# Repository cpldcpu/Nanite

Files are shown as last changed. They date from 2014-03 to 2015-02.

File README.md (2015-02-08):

Nanite 85 
======

The Nanite 85, a nano-sized ATtiny85 devboard with USB Bootloader - most likely the smallest one ever.

The repository holds the Eagle circuit, PCB design data and a software example to handle the soft reset-button.

See [Blog post](http://cpldcpu.wordpress.com/2014/04/25/the-nanite-85/) for more information.

New
===

I teamed up with [Watterott](http://www.watterott.com) on making the Nanite 85 available for everyone. You can get one [here](http://www.watterott.com/de/Wattuino-Nanite85). Note that changes had to be made for manufacturability.

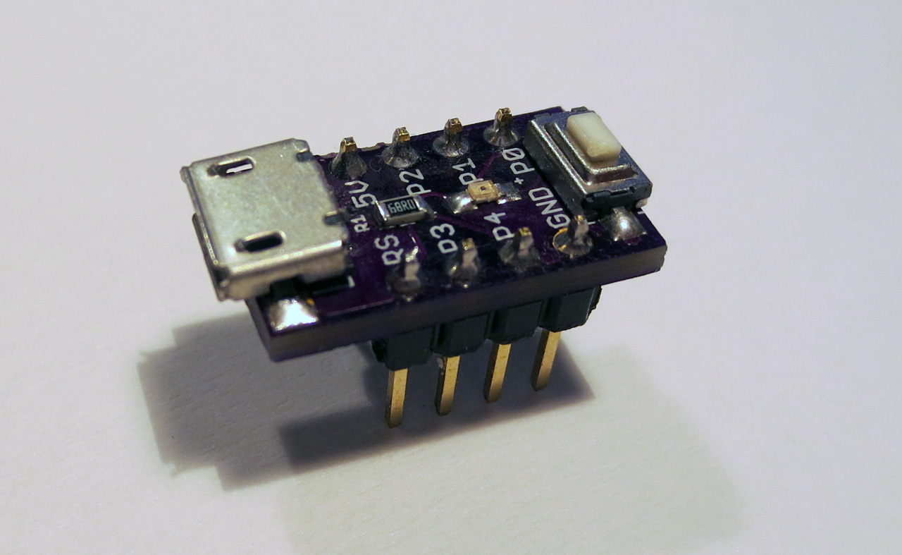
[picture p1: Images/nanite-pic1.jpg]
The Nanite 85


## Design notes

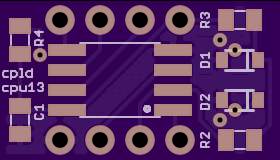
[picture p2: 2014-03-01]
Images/rear.png

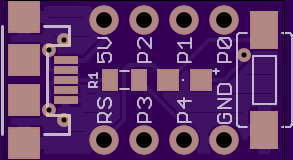
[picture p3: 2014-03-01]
Images/front.png

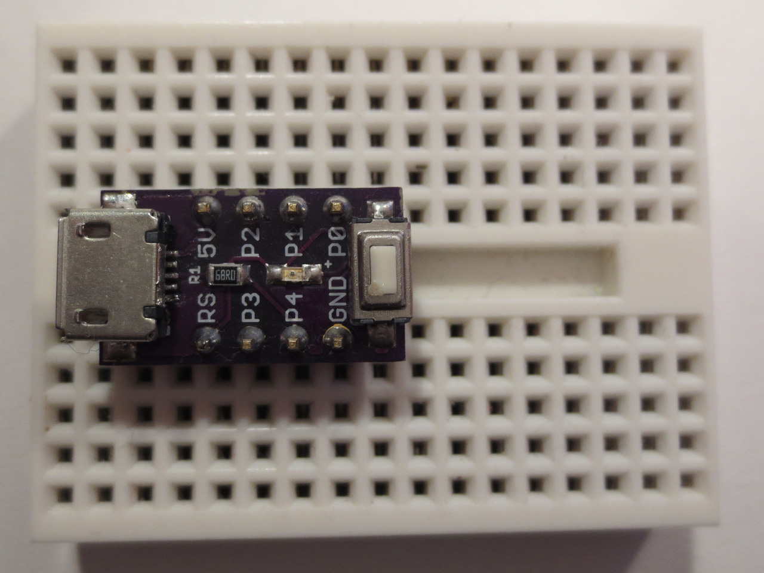
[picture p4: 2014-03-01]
Images/nanite-pic2.jpg

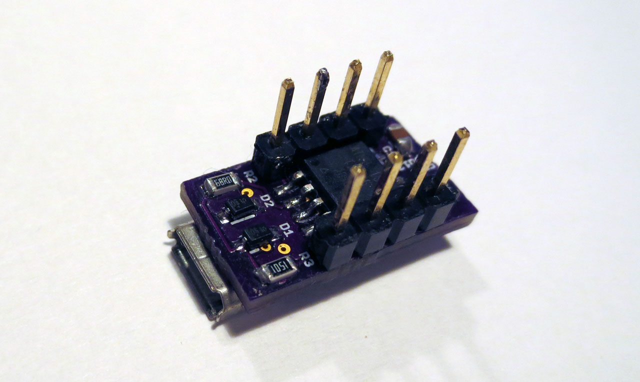
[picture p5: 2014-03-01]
Images/nanite-pic3.jpg

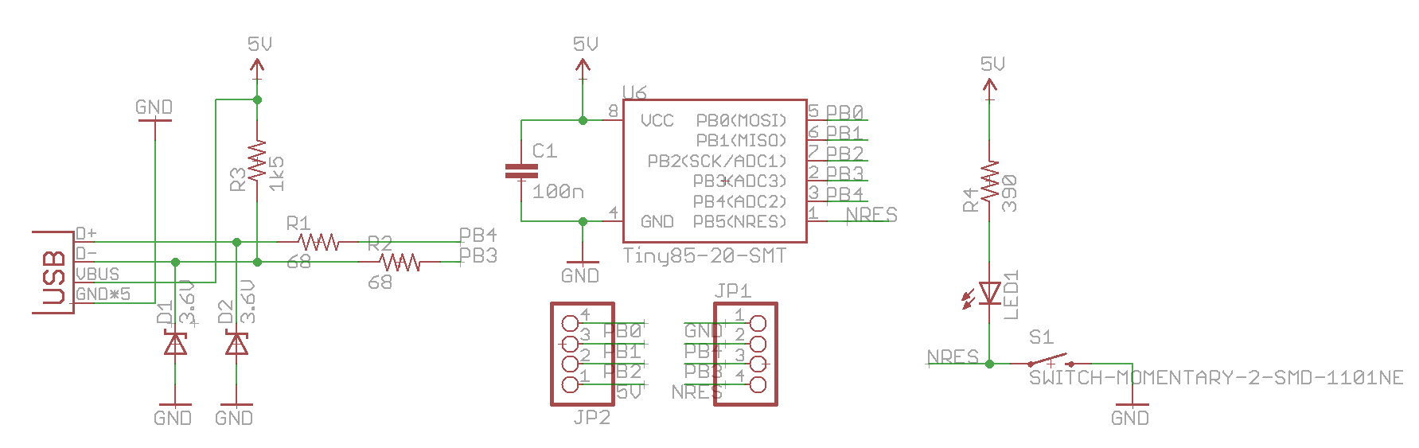
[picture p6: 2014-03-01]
Images/circuit.png

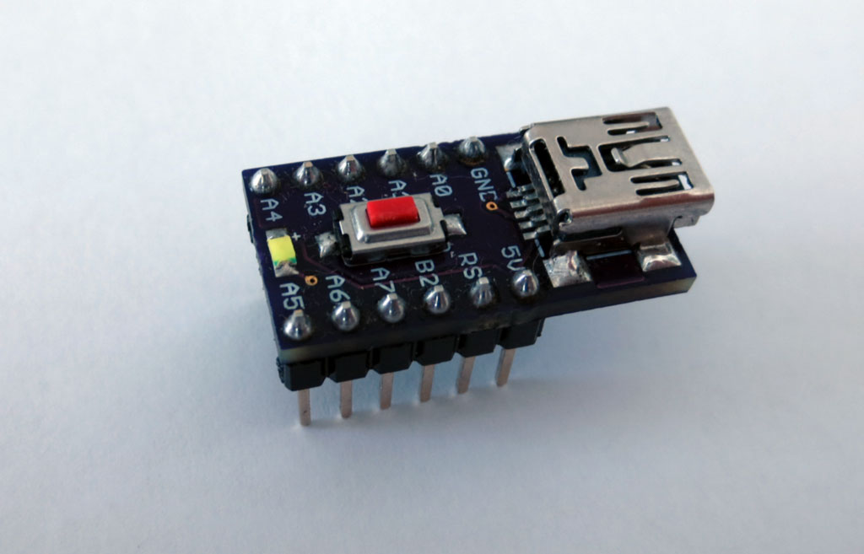
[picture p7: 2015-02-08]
Nanite841/Nanite-841.jpg

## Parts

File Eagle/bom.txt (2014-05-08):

Part     Value                         Device                        Package               
C1       100n                          CAP0805                       0805                 
D1       3.6V                          DIODE-ZENER-BZT52             SOD-323               
D2       3.6V                          DIODE-ZENER-BZT52             SOD-323               
JP1                                    HEADER-1X4ROUND               1X04_ROUND            
JP2                                    HEADER-1X4ROUND               1X04_ROUND            
JP4      USB-MICROB-HOLE               USB-MICROB-HOLE               USB-MICROB-HOLES      
LED1                                   LEDCHIPLED_0805               CHIPLED_0805          
R1       68                            RESISTOR0805-RES              0805                  
R2       68                            RESISTOR0805-RES              0805                  
R3       1k5                           RESISTOR0805-RES              0805                  
R4       390                           RESISTOR0805-RES              0805                  
S1       SWITCH-MOMENTARY-2-SMD-1101NE SWITCH-MOMENTARY-2-SMD-1101NE TACTILE-SWITCH-1101NE 
U6       ATTINY85-SSU                  ATTINY45TINY85-20-SMT         SOIC08           

Notes: 
- This is not an easy soldering project! Recommended order is: 1) Rear side 2) Front side 3) Headears
- The USB micro-b socket is a version that come with two alignment pins. It also works without, but is less mechanically stable.
- The tolerances for mounting of the processor are very tight. Make sure it is aligned properly or you will not be able to install the headers.

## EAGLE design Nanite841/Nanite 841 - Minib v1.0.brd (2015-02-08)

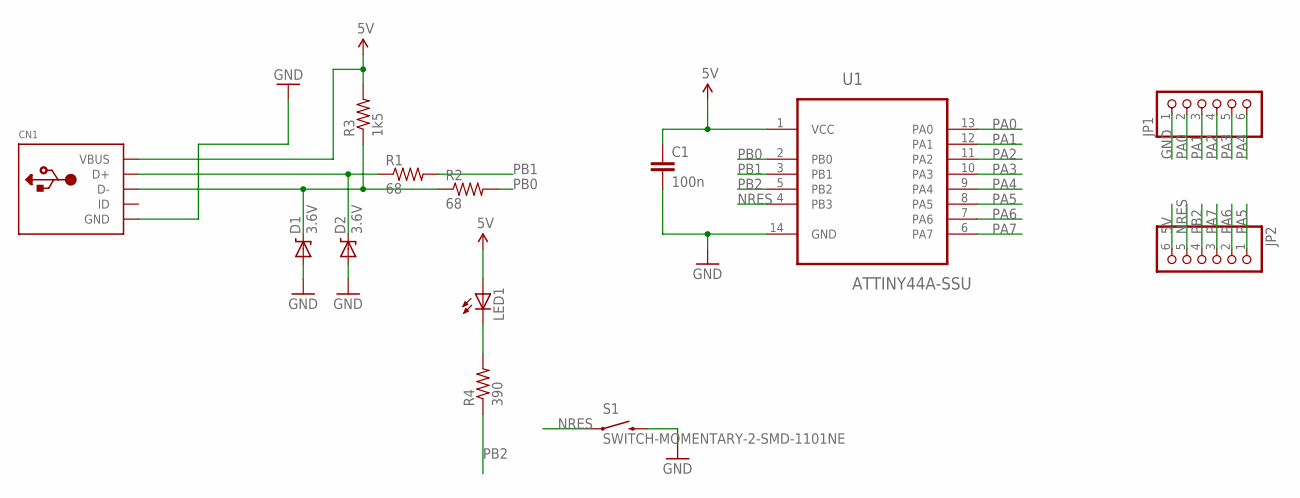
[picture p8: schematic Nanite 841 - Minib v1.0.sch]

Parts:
C1: 100n; 0805
CN1: USBMINIB; USB-MINIB
D1, D2: 3.6V; SOD-323
JP1, JP2: HEADER-1X6ROUND; 1X06_ROUND
LED1: LEDCHIPLED_0805; CHIPLED_0805
R1, R2: 68; 0805
R3: 1k5; 0805
R4: 390; 0805
S1: SWITCH-MOMENTARY-2-SMD-1101NE; TACTILE-SWITCH-1101NE
U1: ATTINY44A-SSU; SOIC127P600X175-14N

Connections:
5V: C1.1, CN1.VBUS, JP2.6, LED1.A, R3.2, U1.1 (VCC)
GND: C1.2, CN1.GND, D1.2 (A), D2.2 (A), JP1.1, S1.P$2 (2), U1.14 (GND)
unnamed: CN1.D-, D1.1 (C), R2.1, R3.1
unnamed: CN1.D+, D2.1 (C), R1.1
unnamed: LED1.C, R4.2
NRES: JP2.5, S1.P$1 (1), U1.4 (PB3)
PA0: JP1.2, U1.13 (PA0)
PA1: JP1.3, U1.12 (PA1)
PA2: JP1.4, U1.11 (PA2)
PA3: JP1.5, U1.10 (PA3)
PA4: JP1.6, U1.9 (PA4)
PA5: JP2.1, U1.8 (PA5)
PA6: JP2.2, U1.7 (PA6)
PA7: JP2.3, U1.6 (PA7)
PB0: R2.2, U1.2 (PB0)
PB1: R1.2, U1.3 (PB1)
PB2: JP2.4, R4.1, U1.5 (PB2)

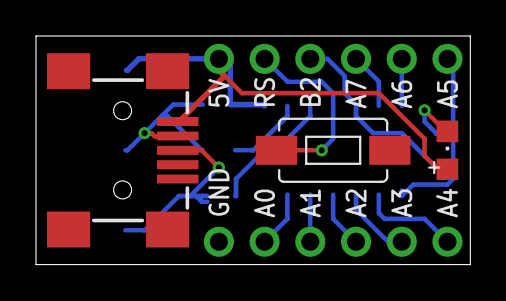
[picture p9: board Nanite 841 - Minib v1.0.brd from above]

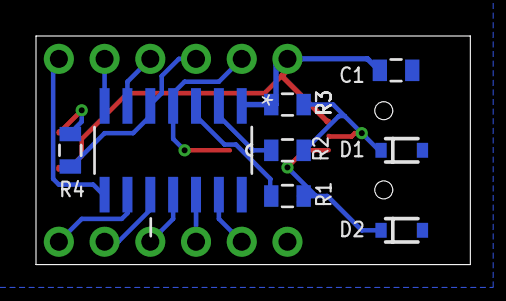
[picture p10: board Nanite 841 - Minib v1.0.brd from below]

Board: 2 copper layers, 24.1 x 12.7 mm, 13 parts (8 on the bottom side), 17 nets.

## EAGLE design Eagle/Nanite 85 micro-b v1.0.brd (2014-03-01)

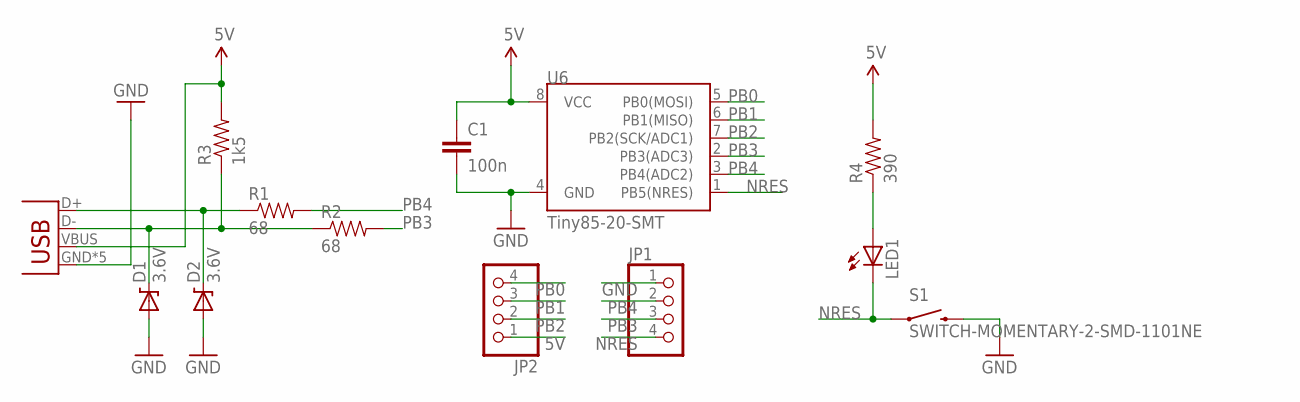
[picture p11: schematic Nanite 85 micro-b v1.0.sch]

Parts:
C1: 100n; 0805
D1, D2: 3.6V; SOD-323
JP1, JP2: HEADER-1X4ROUND; 1X04_ROUND
JP4: USB-MICROB-HOLE-ALLCONNECTED; USB-MICROB-HOLES
LED1: LEDCHIPLED_0805; CHIPLED_0805
R1, R2: 68; 0805
R3: 1k5; 0805
R4: 390; 0805
S1: SWITCH-MOMENTARY-2-SMD-1101NE; TACTILE-SWITCH-1101NE
U6: Tiny85-20-SMT; SO08-EIAJ

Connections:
5V: C1.1, JP2.1, JP4.VBUS, R3.2, R4.2, U6.8 (VCC)
GND: C1.2, D1.2 (A), D2.2 (A), JP1.1, JP4.GND, JP4.MT1 (GND), JP4.MT2 (GND), JP4.P$1 (GND), JP4.P$2 (GND), S1.P$2 (2), U6.4 (GND)
unnamed: D1.1 (C), JP4.D-, R2.1, R3.1
unnamed: D2.1 (C), JP4.D+, R1.1
unnamed: LED1.A, R4.1
NRES: JP1.4, LED1.C, S1.P$1 (1), U6.1 (PB5(NRES))
PB0: JP2.4, U6.5 (PB0(MOSI))
PB1: JP2.3, U6.6 (PB1(MISO))
PB2: JP2.2, U6.7 (PB2(SCK/ADC1))
PB3: JP1.3, R2.2, U6.2 (PB3(ADC3))
PB4: JP1.2, R1.2, U6.3 (PB4(ADC2))

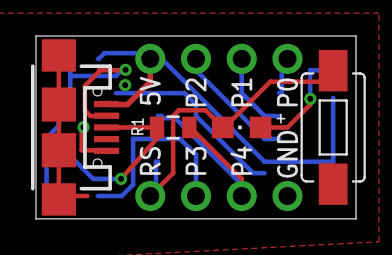
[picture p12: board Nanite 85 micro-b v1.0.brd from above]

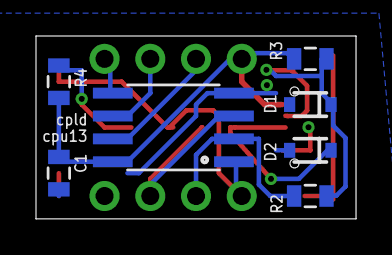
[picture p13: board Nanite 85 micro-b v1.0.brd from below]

Board: 2 copper layers, 17.8 x 10.2 mm, 13 parts (7 on the bottom side), 11 nets.

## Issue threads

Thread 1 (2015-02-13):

upload blink sketch

mulderp, 2015-02-13:
hi,

I am trying to upload a blink sketch:

```
void setup() {
pinMode(0, OUTPUT);
pinMode(1, OUTPUT);
pinMode(2, OUTPUT);

pinMode(3, OUTPUT);

pinMode(4, OUTPUT);

}

void loop() {
pinMode(0, HIGH);
pinMode(1, HIGH);
pinMode(2, HIGH);
pinMode(3, HIGH);
pinMode(4, HIGH);
delay(100);
pinMode(2, LOW);

}
```

I compiled the sketch with ATTiny85 (int 8 MHz)

upload seems to work fine, but no Px LED blinks.

mulderp, 2015-02-13:
```
/Applications/Arduino.app/Contents/Java/hardware/tools/avr/bin/avr-g++ -c -g -Os -w -fno-exceptions -ffunction-sections -fdata-sections -fno-threadsafe-statics -MMD -mmcu=attiny85 -DF_CPU=8000000L -DARDUINO=10600 -DARDUINO_AVR_ATTINY85-8 -DARDUINO_ARCH_AVR -I/Applications/Arduino.app/Contents/Java/hardware/arduino/avr/cores/arduino
```

mulderp, 2015-02-14:
Hm.. maybe my device was damaged. I used another Nanite and this time it worked.

Also, this example sketch is better:

http://digistump.com/wiki/digispark/tutorials/connecting

Closed 2015-02-14.

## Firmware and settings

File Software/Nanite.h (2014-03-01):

/*
 * Nanite.h
 *
 * Created: 27.10.2013 13:43:26
 *  Author: tim , cpldcpu@gmail.com
 */ 


#ifndef NANITE_H_
#define NANITE_H_

#include <util/delay.h>
#include <avr/wdt.h>
#include <avr/io.h>
#include <stdio.h>

/*
	This is usually PB5
*/

#define NANITE_PORT PORTB
#define NANITE_DDR  DDRB
#define NANITE_INP  PINB
#define NANITE_PIN  PB5

/*
*	serial output
*/

#define NANITE_BAUD 9600

void nanite_sendbyte(char);
extern int nanite_putchar(char c, FILE *stream);
 
#define nanite_init_stdout() { \
	static FILE nanite_stdout = FDEV_SETUP_STREAM(nanite_putchar, NULL, _FDEV_SETUP_WRITE); \
	stdout = &nanite_stdout; \
}

/*
	nanite_init
	
	input:  none
	output: none
	
	Initialize pin and turn LED off
*/

#define nanite_init() { \
	NANITE_PORT &=~_BV(NANITE_PIN); \
	NANITE_DDR &=~_BV(NANITE_PIN); \
}

/*
	nanite_poll

	input:  none
	output: none

	nanite_poll_led
	
	input:  boolean to turn the LED on or off
	output: none

	Reads the state of the reset switch. Uses the watch dog timer to issue a reset when the button is pressed.		
*/

#define nanite_poll_led(ledon) { \
	NANITE_DDR &=~_BV(NANITE_PIN); \
	_delay_us(5); \
	if (!(NANITE_INP & _BV(NANITE_PIN))) wdt_enable(WDTO_15MS); \
	if (ledon) NANITE_DDR |=_BV(NANITE_PIN); \
}

#define nanite_poll() { \
	uint8_t nanite_tmp=NANITE_DDR;\
	NANITE_DDR &=~_BV(NANITE_PIN); \
	_delay_us(5); \
	if (!(NANITE_INP & _BV(NANITE_PIN))) wdt_enable(WDTO_15MS); \
	NANITE_DDR =nanite_tmp; \
}


/*
	nanite_led
	
	input:  boolean to turn the LED on or off
	output: none

	Turns LED on or off without polling the reset switch. Use this if you do not want the reset functionality.
*/

#define nanite_setled(ledon) { \
	NANITE_DDR &=~_BV(NANITE_PIN); \
	if (ledon) NANITE_DDR |=_BV(NANITE_PIN); \
}

#define nanite_init_wdt() { \
	wdt_enable(WDTO_500MS); \
	NANITE_PORT &=~_BV(NANITE_PIN); \
	NANITE_DDR &=~_BV(NANITE_PIN); \
}

#define nanite_poll_wdt(a) { \
	NANITE_DDR &=~_BV(NANITE_PIN); \
	_delay_us(5); \
	if (NANITE_INP & _BV(NANITE_PIN)) wdt_reset(); \
	if (a) NANITE_DDR |=_BV(NANITE_PIN); \
}


#endif /* NANITE_H_ */

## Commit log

2014-05-08 added bom
2015-02-08 Nanite 841 first commit
    [Nanite 841 - Minib v1.0.brd, Nanite 841 - Minib v1.0.sch]

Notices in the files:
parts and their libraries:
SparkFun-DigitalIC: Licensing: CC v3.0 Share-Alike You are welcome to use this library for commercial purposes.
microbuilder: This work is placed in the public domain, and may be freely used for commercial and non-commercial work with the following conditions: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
